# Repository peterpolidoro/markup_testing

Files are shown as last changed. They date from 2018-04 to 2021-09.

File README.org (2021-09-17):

# Created 2018-05-17 Thu 12:59
#+OPTIONS: title:nil author:nil email:nil toc:t |:t ^:nil
* Repository Information

- Name :: modular_device_base_3x2
- Version :: 1.2
- License :: Open-Source Hardware
- URL :: https://github.com/janelia-kicad/modular_device_base_3x2
- Author :: Peter Polidoro
- Email :: peter@polidoro.io

** Description

This board is the base of 3x2 format modular devices. It is a breakout board
for the microprocessor, with connections for power, communication, and top
boards.

* Images

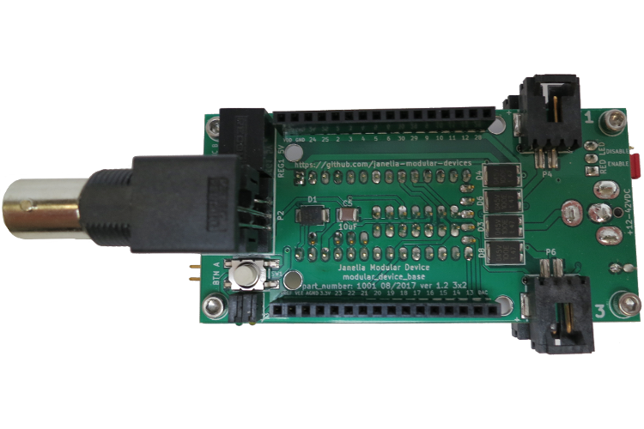
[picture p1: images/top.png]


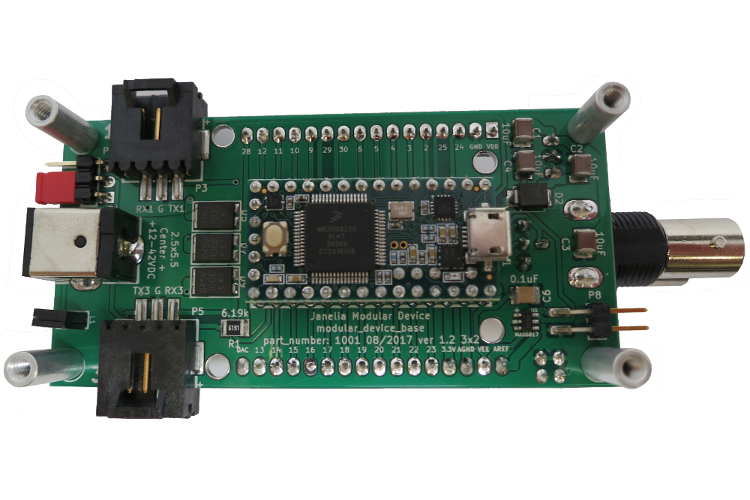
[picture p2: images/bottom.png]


* Schematic

[[file:./schematic/modular_device_base_3x2.pdf][./schematic/modular_device_base_3x2.pdf]]

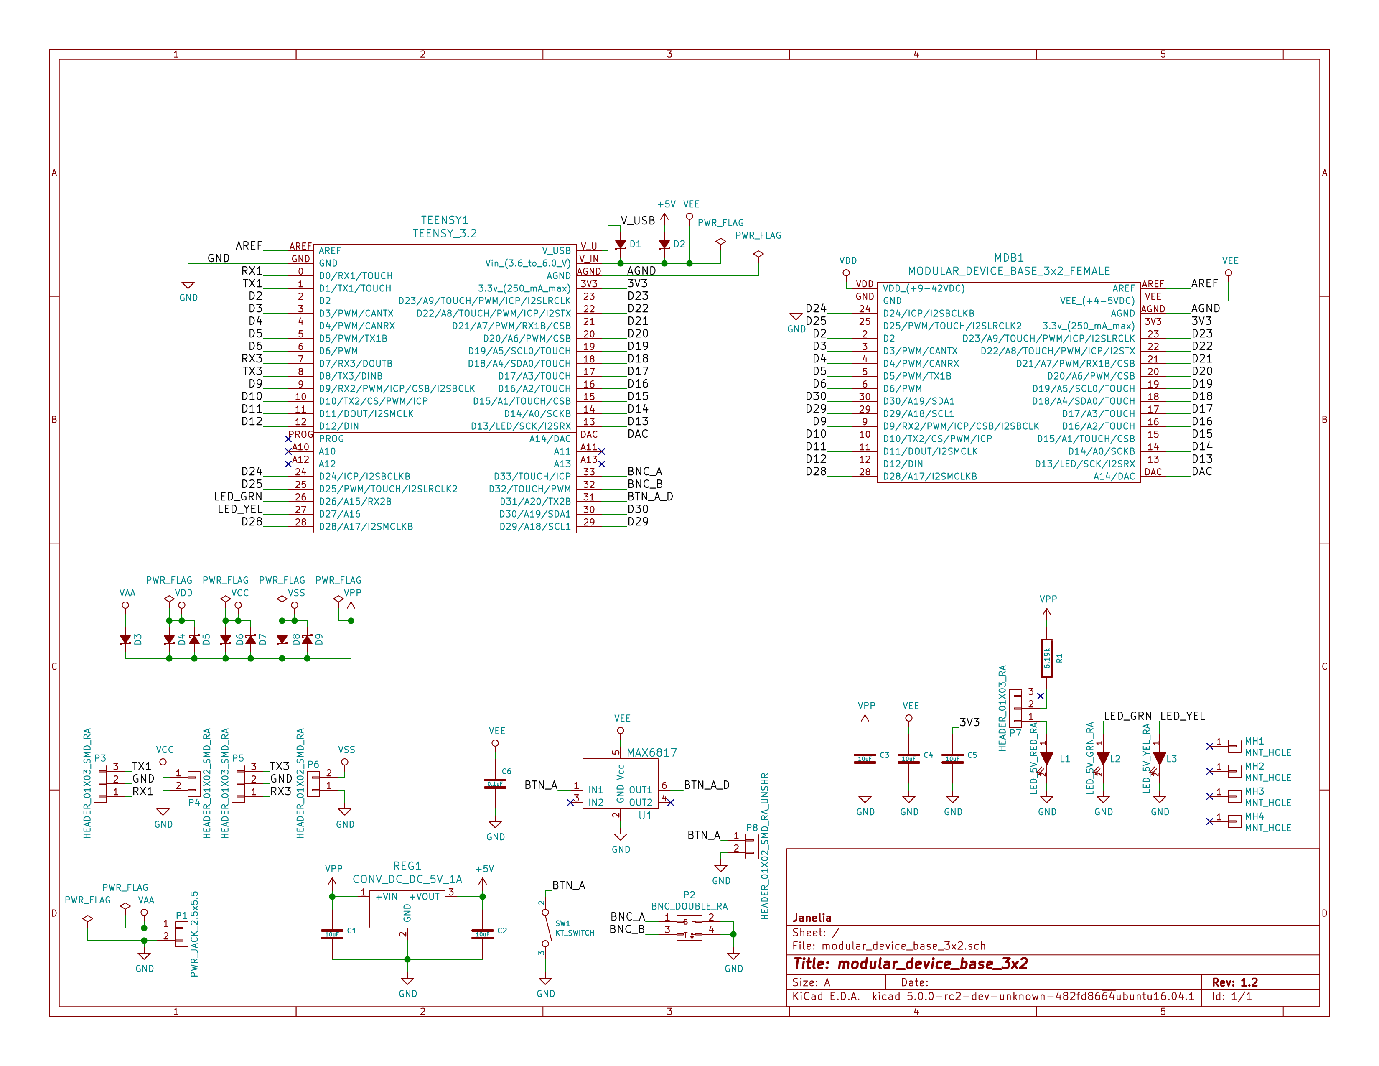
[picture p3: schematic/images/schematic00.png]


* Gerbers

Save gerbers zip file and send to your favorite PCB manufacturer for
fabrication.

[[file:./gerbers/modular_device_base_3x2_v1.2.zip][./gerbers/modular_device_base_3x2_v1.2.zip]]

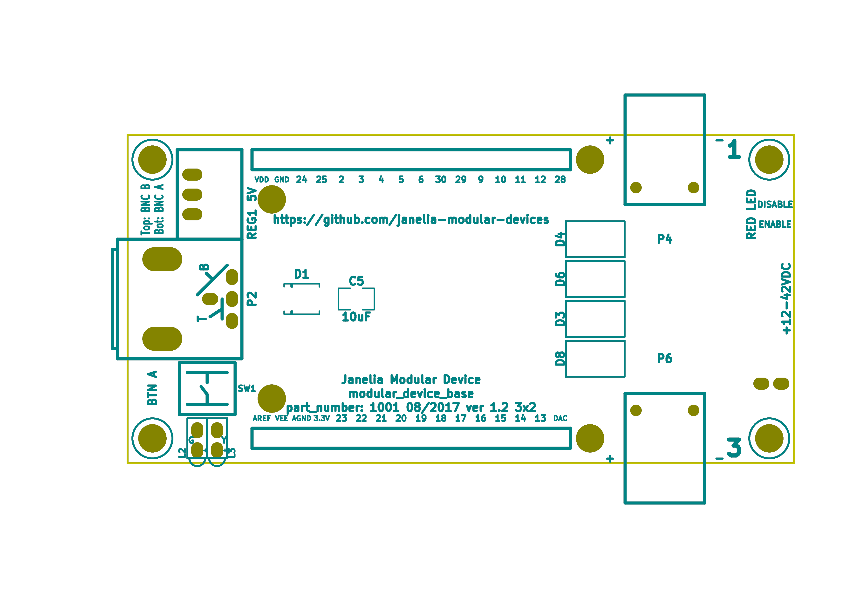
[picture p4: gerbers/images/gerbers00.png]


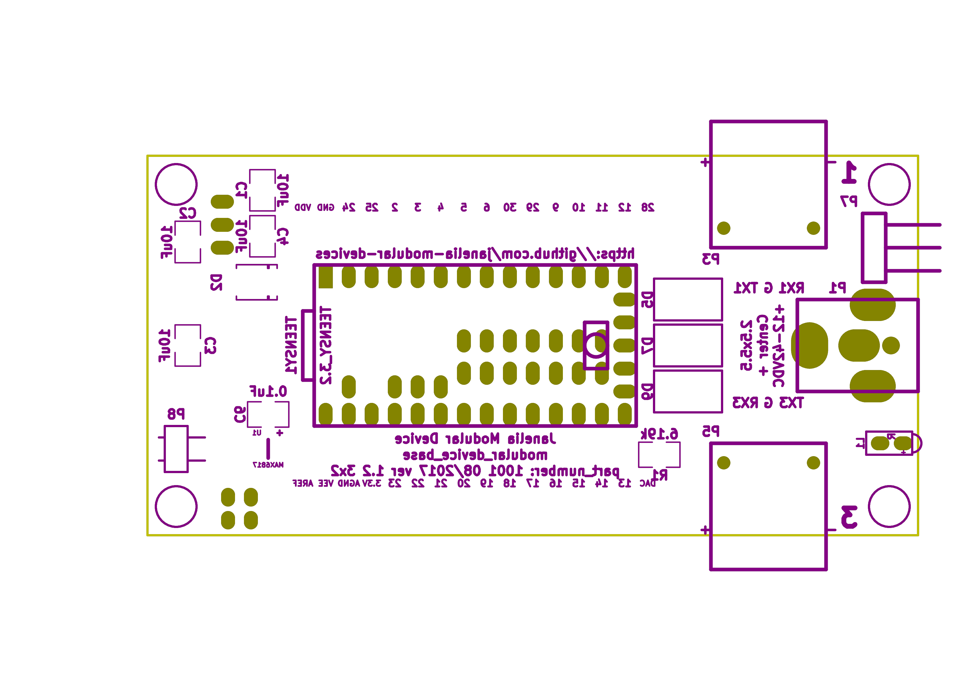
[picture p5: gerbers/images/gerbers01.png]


* Bill of Materials

** PCB Parts

| Item | Reference(s)         | Quantity | PartNumber          | Vendor  | Description                                           |
|------+----------------------+----------+---------------------+---------+-------------------------------------------------------|
|    1 | C1 C2 C3 C4 C5       |        5 | 445-4536-1-ND       | digikey | CAP CER 10UF 50V 10% X7S 1210                         |
|    2 | C6                   |        1 | 399-13229-1-ND      | digikey | CAP CER 0.1UF 100V X7R 1210                           |
|    3 | D1 D2                |        2 | LSM115JE3/TR13CT-ND | digikey | DIODE SCHOTTKY 15V 1A DO214BA                         |
|    4 | D3 D4 D5 D6 D7 D8 D9 |        7 | 568-11697-1-ND      | digikey | DIODE SCHOTTKY 45V 10A CFP15                          |
|    5 | L1                   |        1 | 350-1712-ND         | digikey | LED 2MM 5V RT ANGLE RED PCMNT                         |
|    6 | L2                   |        1 | 350-1717-ND         | digikey | LED 2MM 5V RT ANGLE GREEN PCMNT                       |
|    7 | L3                   |        1 | 350-1719-ND         | digikey | LED 2MM 5V RT ANGLE YELLOW PCMNT                      |
|    8 | MDB1                 |        2 | S7049-ND            | digikey | 16 Position Header Through Hole Female Socket         |
|    9 | MH1 MH2 MH3 MH4      |        4 | 36-2027-ND          | digikey | Round Standoff Threaded 4-40 Aluminum 0.500in 0.187in |
|   10 | P1                   |        1 | CP-063BH-ND         | digikey | CONN PWR JACK DC 2.5X5.5 8A T/H                       |
|   11 | P2                   |        1 | ACX1655-ND          | digikey | CONN BNC JACK R/A 75 OHM PCB                          |
|   12 | P3 P5                |        2 | A100890CT-ND        | digikey | CONN HEADER 3POS R/A SMD GOLD                         |
|   13 | P4 P6                |        2 | A100903CT-ND        | digikey | CONN HEADER 2POS R/A SMD GOLD                         |
|   14 | P7                   |        1 | 732-5336-ND         | digikey | CONN HEADER 3 POS RA 2.54                             |
|   15 | P8                   |        1 | SAM10781-ND         | digikey | CONN HEADER 2POS .100in SNGL SMD                      |
|   16 | R1                   |        1 | P6.19KAACT-ND       | digikey | RES SMD 6.19K OHM 1% 1/2W 1210                        |
|   17 | REG1                 |        1 | 945-1395-5-ND       | digikey | CONV DC/DC 1A 5V OUT SIP VERT                         |
|   18 | SW1                  |        1 | CKN1860CT-ND        | digikey | SWITCH TACTILE SPST-NO 1VA 32V                        |
|   19 | TEENSY1              |        1 | 1568-1231-ND        | digikey | DEV TEENSY 3.2 13736                                  |
|   20 | U1                   |        1 | MAX6817EUT+TCT-ND   | digikey | IC DEBOUNCER SWITCH DUAL SOT23-6                      |

** Supplemental Parts

| Item | Quantity | PartNumber    | Vendor  | Description                                                              |
|------+----------+---------------+---------+--------------------------------------------------------------------------|
|    1 |        1 | 62-1187-ND    | digikey | AC/DC DESKTOP ADAPTER 24V 90W                                            |
|    2 |        1 | EPS594-ND     | digikey | 30 WATT DESKTOP POWER SUPPLY 24V                                         |
|    3 |        1 | 993-1037-ND   | digikey | CORD 3COND NEMA PLUG 320-C5                                              |
|    4 |        1 | A106625CT-ND  | digikey | 14 Positions Header Unshrouded Breakaway Connector 0.100in 2 row SMD     |
|    5 |        2 | S1011EC-24-ND | digikey | 24 Positions Header Unshrouded Breakaway Connector 0.100in 1 row Through |
|    6 |        1 | S9001-ND      | digikey | CONN JUMPER SHORTING GOLD FLASH                                          |
|    7 |        1 | AE10342-ND    | digikey | CABLE USB-A TO MICRO USB-B 2M                                            |

** Vendor Parts Lists

[[file:./bom/digikey_parts.csv][./bom/digikey_parts.csv]]

[[file:./bom/supplemental_digikey_parts.csv][./bom/supplemental_digikey_parts.csv]]

* Supplemental Documentation

** Assembly Instructions

- Cut the bottom trace on the Teensy board that connects the 5V pads according
  to these instructions [[https://www.pjrc.com/teensy/external_power.html]].
- Solder through hole header pins into every Teensy 0.1 inch header hole.
- Solder surface mount header pins onto the bottom of the Teensy making sure
  they are properly aligned.
- Solder surface mount and through hole components onto the pcb.
- Solder the Teensy into the pcb making sure it is properly aligned.
- Connect header jumper to RED LED enable pins.

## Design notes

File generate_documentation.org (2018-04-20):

#+MACRO: name modular_device_base_3x2
#+MACRO: version 1.2
#+EXPORT_FILE_NAME: README
#+TITLE: generate_documentation
#+AUTHOR: Peter Polidoro
#+EMAIL: peterpolidoro@gmail.com
#+OPTIONS: title:nil author:nil email:nil toc:t |:t ^:nil

* Description                                                      :noexport:
  This file generates documentation into the desired format when it is exported
  by emacs org-mode.

* Setup                                                            :noexport:
  Dependencies:
  - imagemagik #To generate images
  - texlive-latex-extra #To generate pdf files.

  Kicad:
  - Plot schematic in ./schematic/ in pdf format.
  - Generate bill of materials.
  - Plot gerbers for all important layers in ./gerbers/ in gerber format, using
    Protel filename extensions.
  - Generate drill file in ./gerbers/ in gerber format.
  - Print F.SilkS and B.SilkS in ./gerbers/ in pdf format.

  Images:
  - Take photo of top of board and save it to ./images/top.png
  - Take photo of bottom of board and save it to ./images/bottom.png

* Data                                                             :noexport:
  #+TBLNAME: repository-info
  | {{{name}}}    |
  | {{{version}}} |

* Repository Information
  - Name :: {{{name}}}
  - Version :: {{{version}}}
  - Author :: {{{author}}}
  - Email :: {{{email}}}
  - License :: Open-Source Hardware

  This board is the base of 3x2 format modular devices. It is a breakout board
  for the microprocessor, with connections for power, communication, and top
  boards.

* Images

  #+BEGIN_SRC sh :exports results :results raw
  TOP=./images/top.png
  if [ -f $TOP ]; then
    echo "[[file:$TOP]]\n"
  fi
  BOTTOM=./images/bottom.png
  if [ -f $BOTTOM ]; then
    echo "[[file:$BOTTOM]]\n"
  fi
  #+END_SRC
* Schematic

  #+BEGIN_SRC sh :exports results :results raw
  for i in ./schematic/*.pdf; do
    echo "[[file:$i][$i]]\n"
  done
  #+END_SRC
  #+BEGIN_SRC sh :exports results :results raw
  rm -rf ./schematic/images/
  mkdir ./schematic/images
  convert -density 300 -depth 8 -quality 85 ./schematic/*.pdf ./schematic/images/schematic%02d.png
  for i in ./schematic/images/*.png; do
    echo "[[file:$i]]\n"
  done
  #+END_SRC
* Gerbers

  Save gerbers zip file and send to your favorite PCB manufacturer for
  fabrication.

  #+HEADER: :var name=repository-info[0,0]
  #+HEADER: :var version=repository-info[1,0]
  #+BEGIN_SRC sh :exports results :results raw
    rm ./gerbers/*.zip
    ZIP_FILENAME=./gerbers/${name}_v${version}.zip
    zip $ZIP_FILENAME ./gerbers/*.g* ./gerbers/*.drl -q
    for i in ./gerbers/*.zip; do
      echo "[[file:$i][$i]]\n"
    done
  #+END_SRC
  #+BEGIN_SRC sh :exports results :results raw
  rm -rf ./gerbers/images/
  mkdir ./gerbers/images
  convert -density 300 -depth 8 -quality 85 -rotate "90" ./gerbers/*.pdf ./gerbers/images/gerbers%02d.png
  for i in ./gerbers/images/*.png; do
    echo "[[file:$i]]\n"
  done
  #+END_SRC
* Bill of Materials
** PCB Parts
   [[./bom/bom_pcb.csv][./bom/bom_pcb.csv]]
   #+BEGIN_SRC sh :exports results
  cat ./bom/bom_pcb.csv
   #+END_SRC

** Additional Parts
   [[./bom/bom_pcb_add.csv][./bom/bom_pcb_add.csv]]
   #+INCLUDE: "./bom/bom_pcb_add.org"
  #  #+BEGIN_SRC sh :exports results
  # cat ./bom/bom_pcb_add.csv
  #  #+END_SRC
** Vendor Parts Lists
   #+BEGIN_SRC sh :exports results :results raw
    for i in ./bom/*order*.csv; do
      echo "[[file:$i][$i]]\n"
    done
   #+END_SRC

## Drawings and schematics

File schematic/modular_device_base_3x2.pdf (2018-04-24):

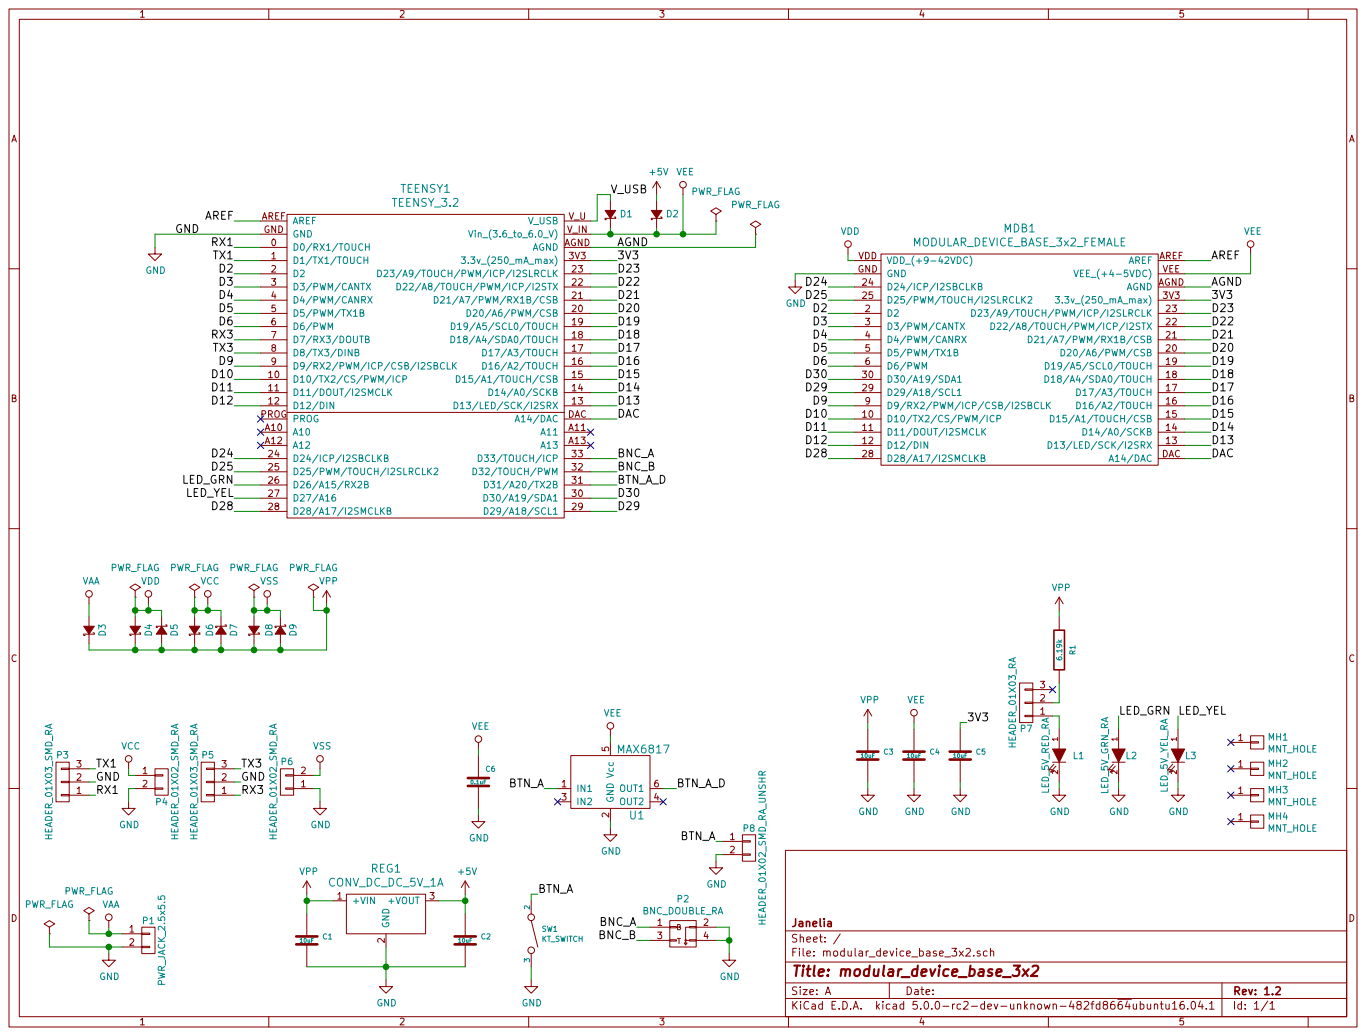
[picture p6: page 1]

File: modular_device_base_3x2.sch Sheet: / Janelia

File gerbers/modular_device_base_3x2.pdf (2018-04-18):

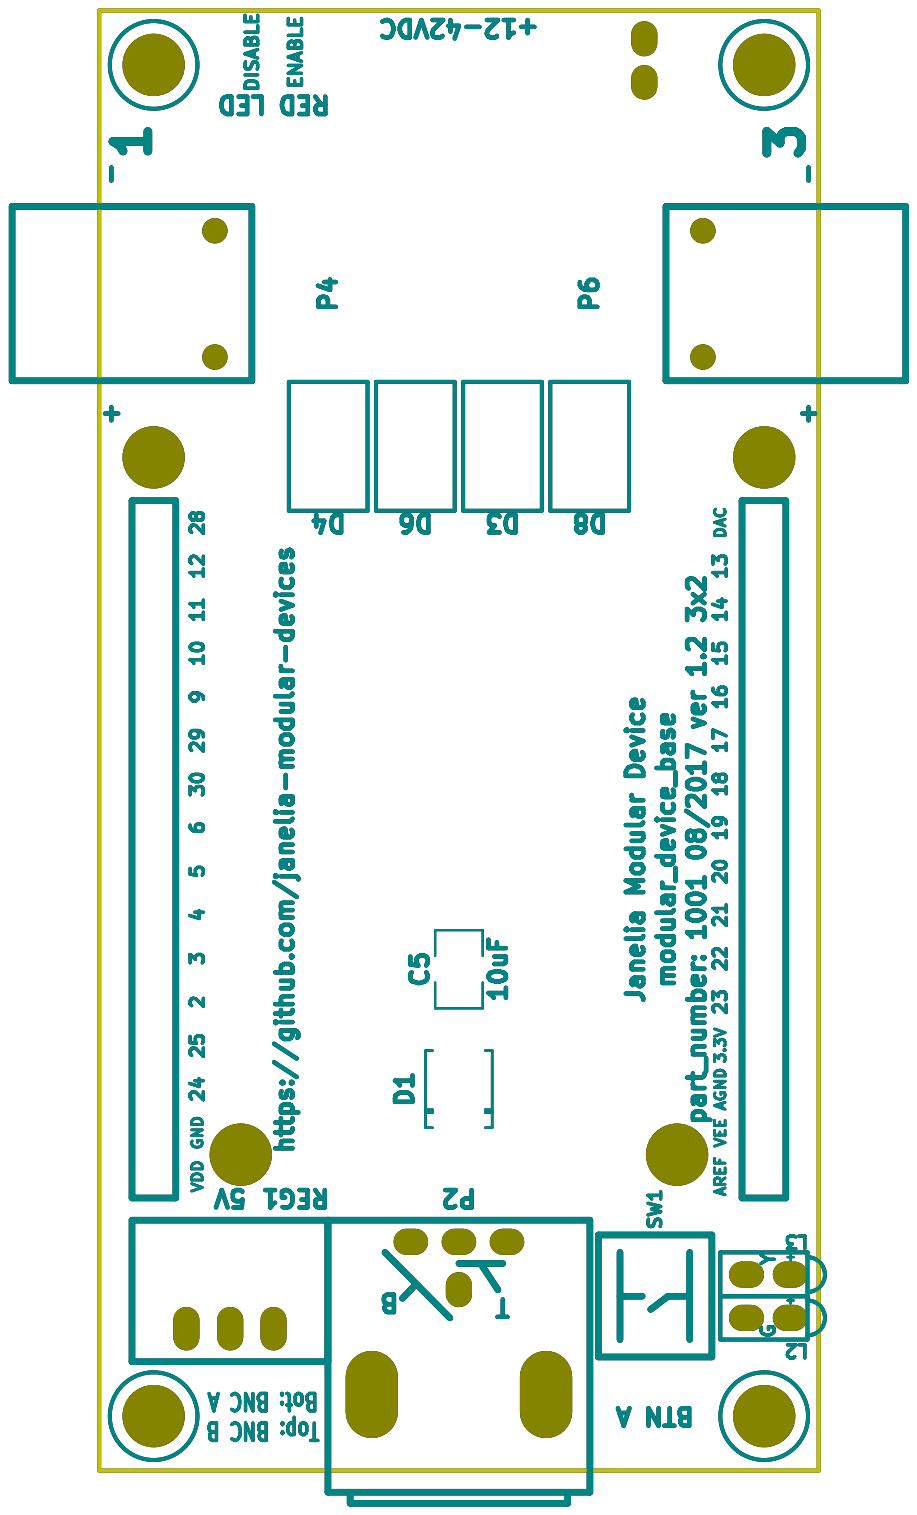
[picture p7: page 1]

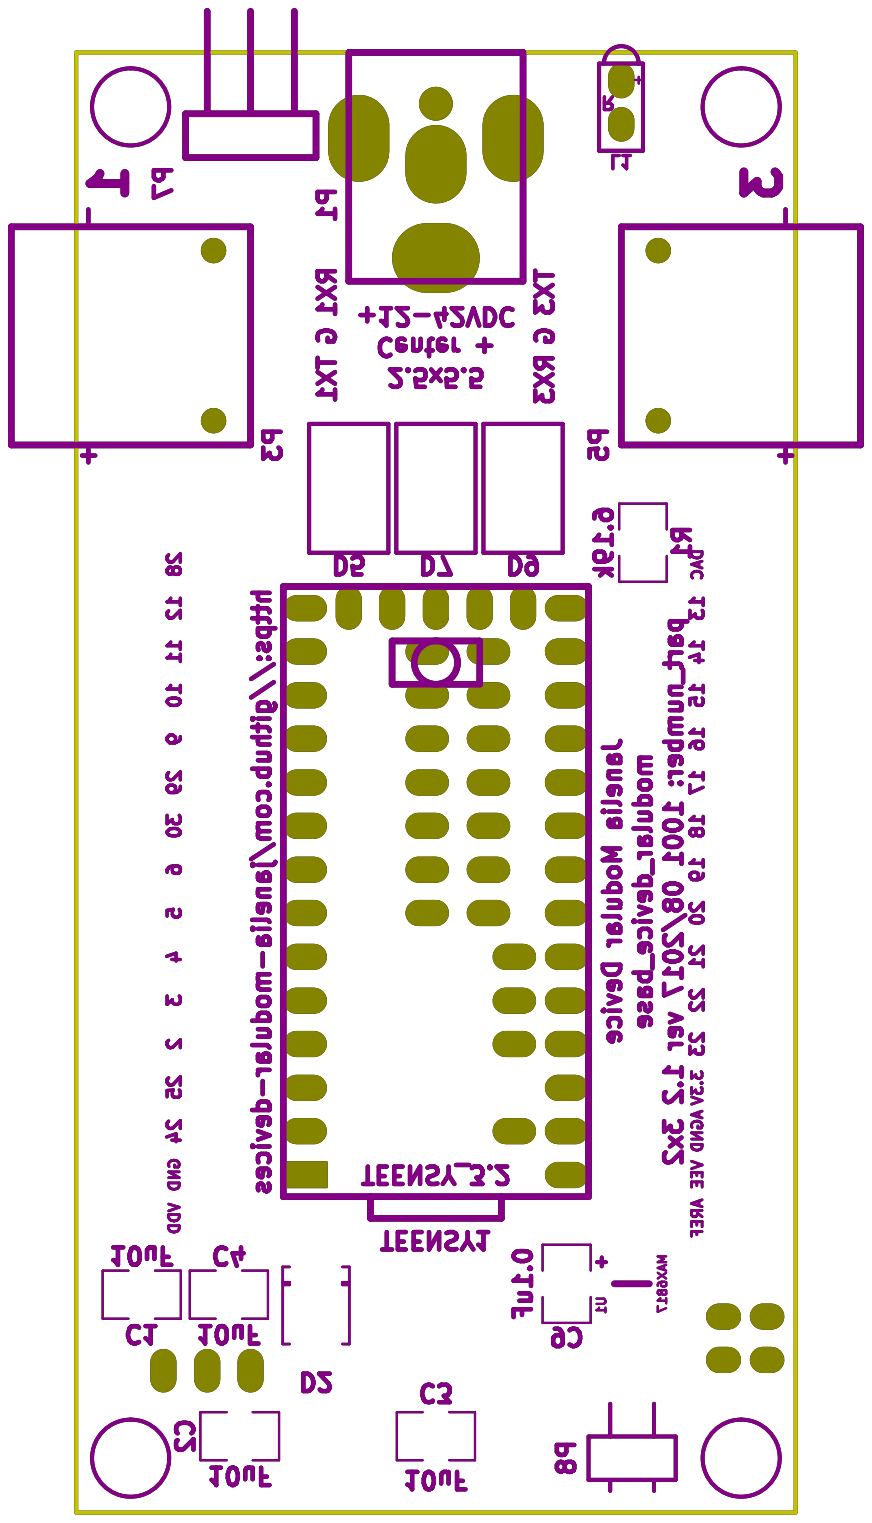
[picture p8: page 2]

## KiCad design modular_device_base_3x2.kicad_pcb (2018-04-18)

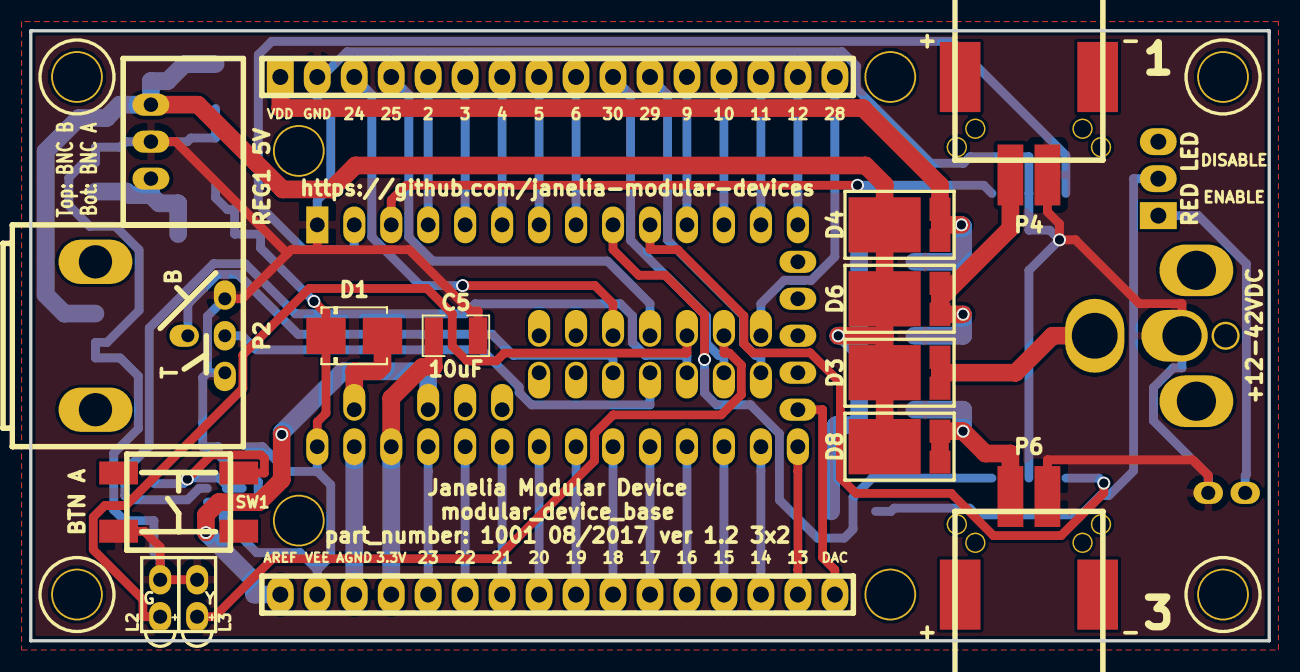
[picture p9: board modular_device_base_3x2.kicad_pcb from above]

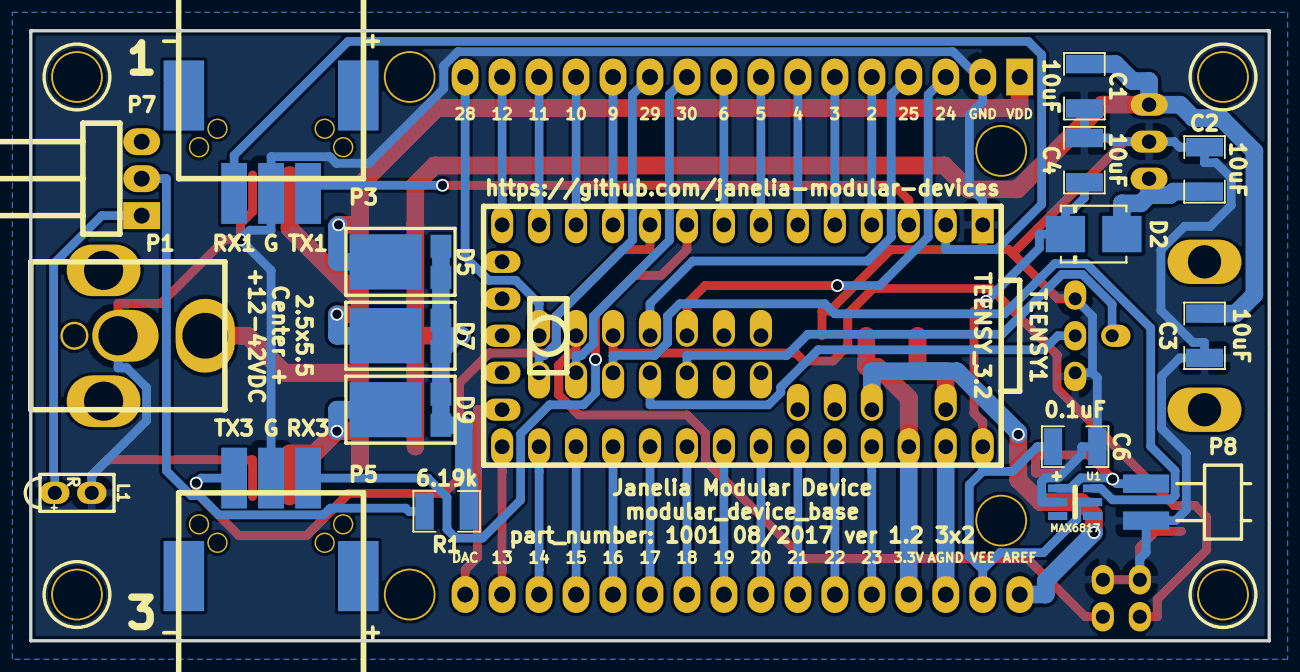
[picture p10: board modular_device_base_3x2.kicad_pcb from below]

Board: 2 copper layers, 85.1 x 41.9 mm, 36 parts (18 on the bottom side), 50 nets.

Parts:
C1, C2, C3, C4, C5: 10uF; SM1210
C6: 0.1uF; SM1210
D1, D2: diode_schottky_15V_1A; DO-214BA
D3, D4, D5, D6, D7, D8, D9: diode_schottky_45V_10A; CFP15
L1: LED_5V_RED_RA; LED_555-2XXX
L2: LED_5V_GRN_RA; LED_555-2XXX
L3: LED_5V_YEL_RA; LED_555-2XXX
MDB1: MODULAR_DEVICE_BASE_3x2_FEMALE; MODULAR_DEVICE_BASE_3X2_FEMALE
MH1, MH2, MH3, MH4: MNT_HOLE; MOUNTING_HOLE_4-40
P1: PWR_JACK_2.5x5.5; DCJACK_2PIN_HIGHCURRENT
P2: BNC_DOUBLE_RA; BNC_DOUBLE
P3, P5: HEADER_01X03_SMD_RA; Header_3_Pin_SMD_RA
P4, P6: HEADER_01X02_SMD_RA; Header_2_Pin_SMD_RA
P7: HEADER_01X03_RA; Header_3_Pin_RA
P8: HEADER_01X02_SMD_RA_UNSHR; Header_2_Pin_SMD_RA_UNSHR
R1: 6.19k; SM1210
REG1: CONV_DC_DC_5V_1A; DC_DC_CONV_R78C
SW1: KT_SWITCH
TEENSY1: TEENSY_3.2
U1: MAX6817

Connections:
+5V: C2.1, D2.2, REG1.3
/3V3: C5.1, MDB1.3V3, TEENSY1.3V3
/AGND: MDB1.AGND, TEENSY1.AGND
/AREF: MDB1.AREF, TEENSY1.AREF
/BNC_A: P2.1, TEENSY1.33
/BNC_B: P2.3, TEENSY1.32
/BTN_A: P8.1, SW1.2, U1.1
/BTN_A_D: TEENSY1.31, U1.6
/D2: MDB1.2, TEENSY1.2
/D3: MDB1.3, TEENSY1.3
/D4: MDB1.4, TEENSY1.4
/D5: MDB1.5, TEENSY1.5
/D6: MDB1.6, TEENSY1.6
/D9: MDB1.9, TEENSY1.9
/D10: MDB1.10, TEENSY1.10
/D11: MDB1.11, TEENSY1.11
/D12: MDB1.12, TEENSY1.12
/D13: MDB1.13, TEENSY1.13
/D14: MDB1.14, TEENSY1.14
/D15: MDB1.15, TEENSY1.15
/D16: MDB1.16, TEENSY1.16
/D17: MDB1.17, TEENSY1.17
/D18: MDB1.18, TEENSY1.18
/D19: MDB1.19, TEENSY1.19
/D20: MDB1.20, TEENSY1.20
/D21: MDB1.21, TEENSY1.21
/D22: MDB1.22, TEENSY1.22
/D23: MDB1.23, TEENSY1.23
/D24: MDB1.24, TEENSY1.24
/D25: MDB1.25, TEENSY1.25
/D28: MDB1.28, TEENSY1.28
/D29: MDB1.29, TEENSY1.29
/D30: MDB1.30, TEENSY1.30
/DAC: MDB1.DAC, TEENSY1.DAC
/LED_GRN: L2.1, TEENSY1.26
/LED_YEL: L3.1, TEENSY1.27
/RX1: P3.1, TEENSY1.0
/RX3: P5.1, TEENSY1.7
/TX1: P3.3, TEENSY1.1
/TX3: P5.3, TEENSY1.8
/V_USB: D1.2, TEENSY1.V_U
GND: C1.2, C2.2, C3.2, C4.2, C5.2, C6.2, L1.2, L2.2, L3.2, MDB1.GND, P1.2, P2.2, P2.4, P3.2, P4.2, P5.2, P6.1, P8.2, REG1.2, SW1.3, TEENSY1.GND, U1.2
unnamed: L1.1, P7.1
unnamed: P7.2, R1.2
VAA: D3.2, P1.1
VCC: D6.2, D7.1, P4.1
VDD: D4.2, D5.1, MDB1.VDD
VEE: C4.1, C6.1, D1.1, D2.1, MDB1.VEE, TEENSY1.V_IN, U1.5
VPP: C1.1, C3.1, D3.1, D4.1, D5.2, D6.1, D7.2, D8.1, D9.2, R1.1, REG1.1
VSS: D8.2, D9.1, P6.2

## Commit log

2018-04-13 csv and org testing.
    [bom_pcb.csv]
2018-04-18 Added modular_device_base_3x2 files for testing.
    [bom_pcb.csv, bom_pcb_add.csv, digikey_order.csv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]
2018-04-18 Test gerbers.
2018-04-18 Make new gerber images.
2018-04-18 Create links to schematic and gerbers.
2018-04-20 Convert bom to org file.
    [bom_pcb_add.csv]
2018-04-24 Revert back to modular_device_base_3x2.
    [bom_pcb_add.csv]
2018-04-24 Saved new files from kicad.
    [modular_device_base_3x2-B.Cu.gbl, modular_device_base_3x2-B.Mask.gbs, modular_device_base_3x2-B.SilkS.gbo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]
2018-04-26 Removed bom files.
    [bom_pcb.csv, bom_pcb_add.csv, digikey_order.csv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]
2018-04-26 New test results.
    [digikey_parts.csv]
2018-05-15 Filtered README.org.
2018-05-16 Add supplemental bom.
2018-05-17 Test new changes.
    [supplemental_digikey_parts.csv]
